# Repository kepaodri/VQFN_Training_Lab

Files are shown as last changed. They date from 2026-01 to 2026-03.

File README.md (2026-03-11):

# VQFN_Training_Lab
PCB Design for a VQFN and DFN package soldering practice board using an LDO regulator.
The purpose of this project is to give different hobbyists without prior experience with this type of package the opportunity to perform soldering tests to reach a good level of mastery. Soldering can be done for example using both reflow hot plate and/or hot air gun. 

## Project Description
This project features a power supply circuit centered on the AP7361C (DFN) LDO regulator. It converts a 2.2V to 6.0V input into a stable 3.3V output with ±1% accuracy. To manage power, SW1 (POWER ON) and SW2 (RESET) pulses are debounced by a 74LVC2G14 Schmitt-Trigger inverter (TSSOP6). A 74AHCT32 (VQFN) OR gate creates a latch, while a 74HCT08 (VQFN) AND gate acts as a kill switch to maintain Enable signal only if the latch is active and RESET is not pressed. 2 green LEDs (D1, D2) provide visual feedback status for the +5V and +3V3 rails.

### Hardware Features
- Input Voltage Range: 2.2V - 6V
- Output Voltage: 3.3V Fixed
- Output voltage accuracy: +-1%
- Max Current: 1.5A

### PCB Features
- Layers: 2
- Thickness: 1.6mm
- Width: 45mm
- Heigth: 50mm

### 3D Render
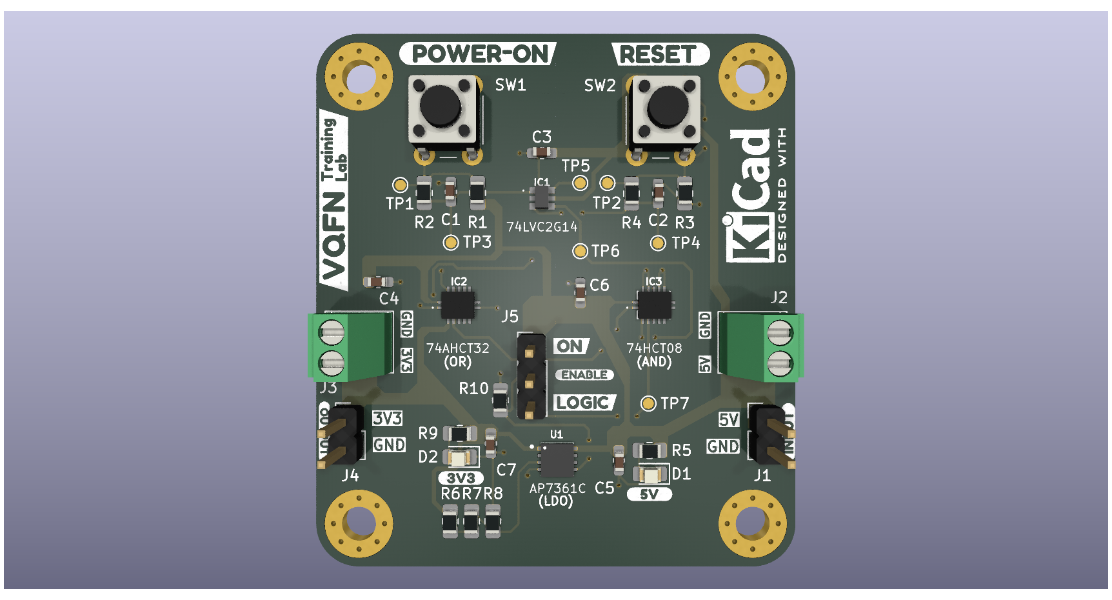
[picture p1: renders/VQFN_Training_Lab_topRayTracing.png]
Top View

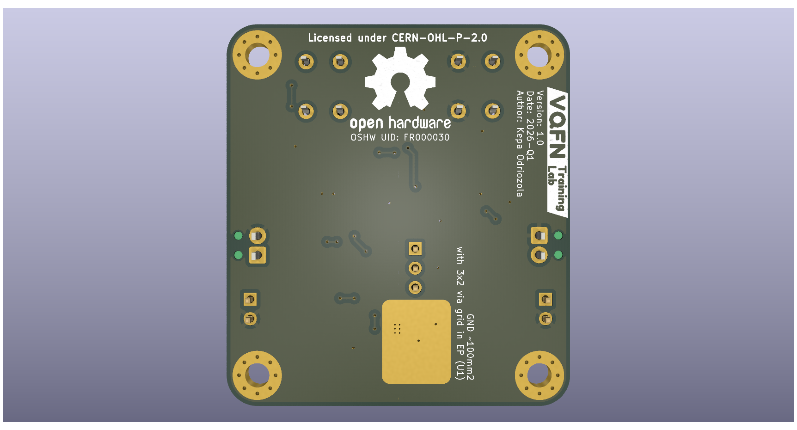
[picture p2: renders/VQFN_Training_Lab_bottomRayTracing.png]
Bot View


## Tools Used
KiCad: 9.0.4

## Licensing and Open Source Hardware
This project is certified as \*\*Open Source Hardware\*\*. 

### Hardware License
The hardware design files are licensed under the \*\*CERN Open Hardware Licence Version 2 - Permissive (CERN-OHL-P-2.0)\*\*. 
> You may redistribute and modify this documentation and build products based on it under the terms of the CERN-OHL-P v2.0.
### Documentation License
All associated documentation, including manuals and images, is licensed under \*\*Creative Commons Attribution-ShareAlike 4.0 International (CC BY-SA 4.0)\*\*.

OSHW_UID

## Disclaimer
\*\*This design is provided "AS-IS" without any express or implied warranties.\*\* The author is not responsible for any damage to equipment, fire, or personal injury resulting from the assembly or use of this PCB.

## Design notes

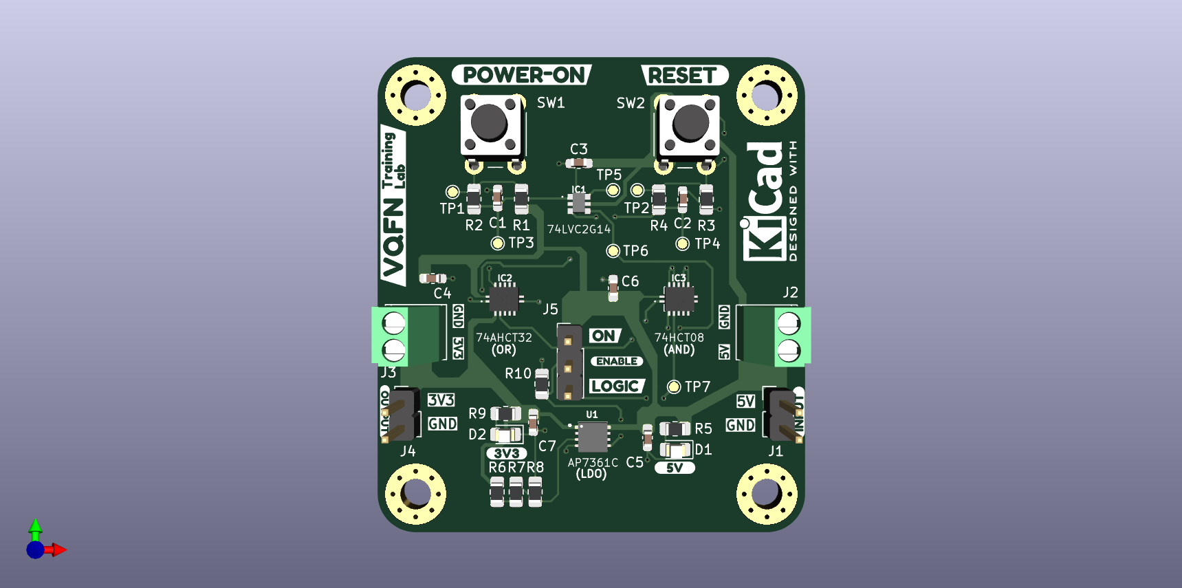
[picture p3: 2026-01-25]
renders/VQFN_Training_Lab_top.png

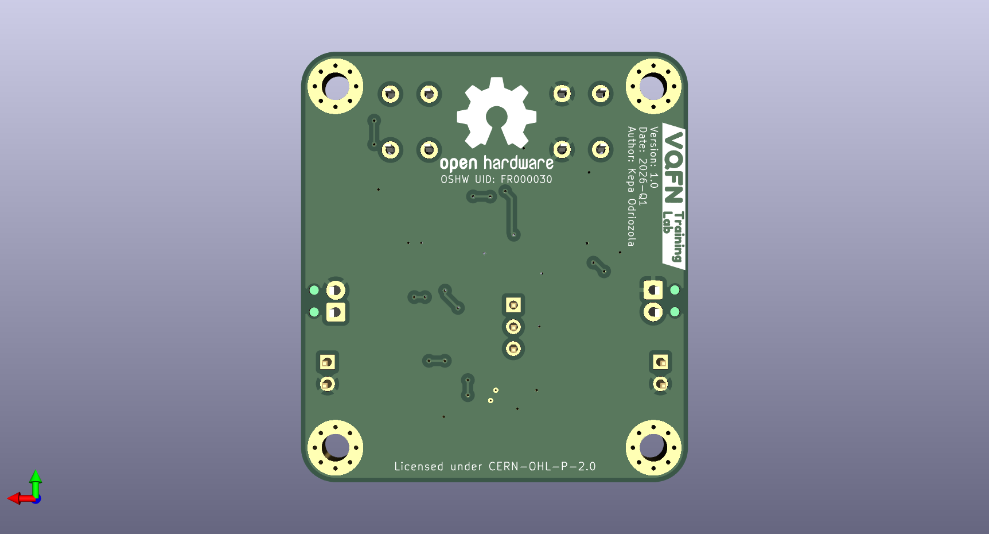
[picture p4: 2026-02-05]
renders/VQFN_Training_Lab_bottom.png

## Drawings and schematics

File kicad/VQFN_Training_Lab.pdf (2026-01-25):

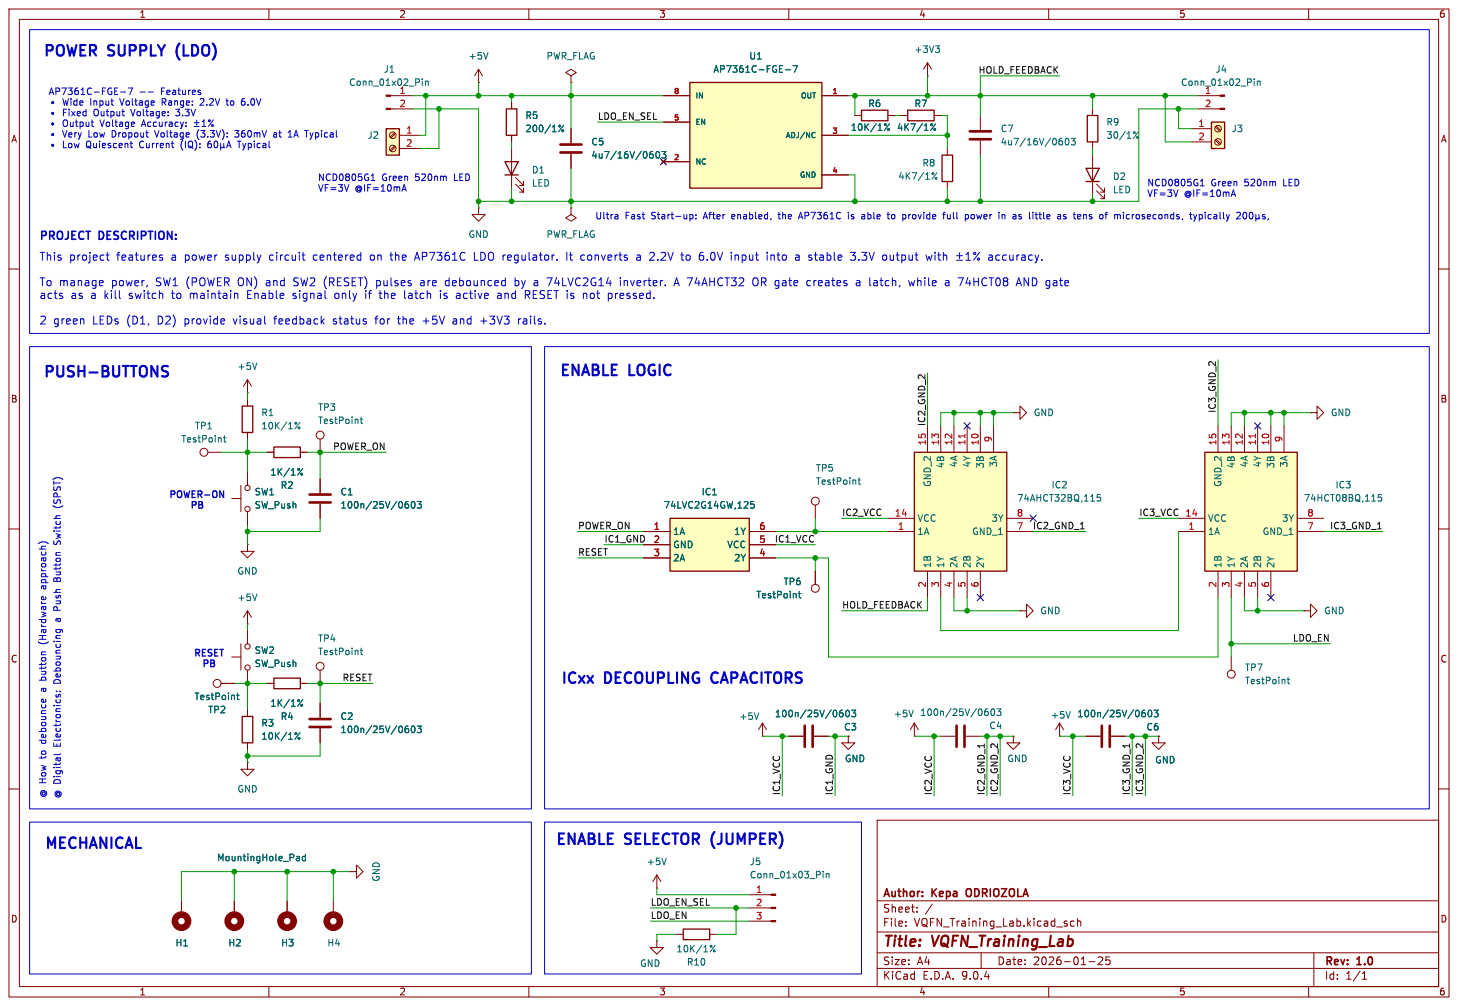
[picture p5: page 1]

+3V3 PWR_FLAG
VF=3V @IF=10mA RESET PB

þÿ "Fixed Output Voltage: 3.3V
þÿ "Output Voltage Accuracy: þÿ±1%
þÿ "Very Low Dropout Voltage (3.3V): 360mV at 1A Typical
þÿ "Low Quiescent Current (IQ): þÿ60µATypical

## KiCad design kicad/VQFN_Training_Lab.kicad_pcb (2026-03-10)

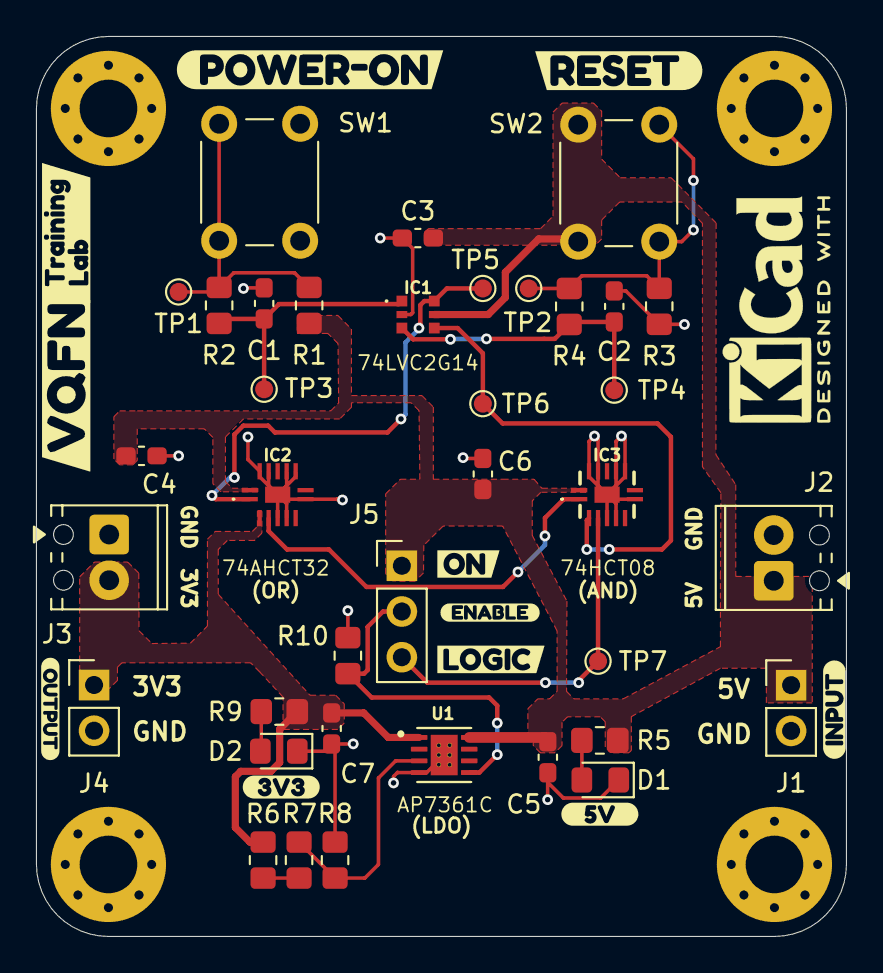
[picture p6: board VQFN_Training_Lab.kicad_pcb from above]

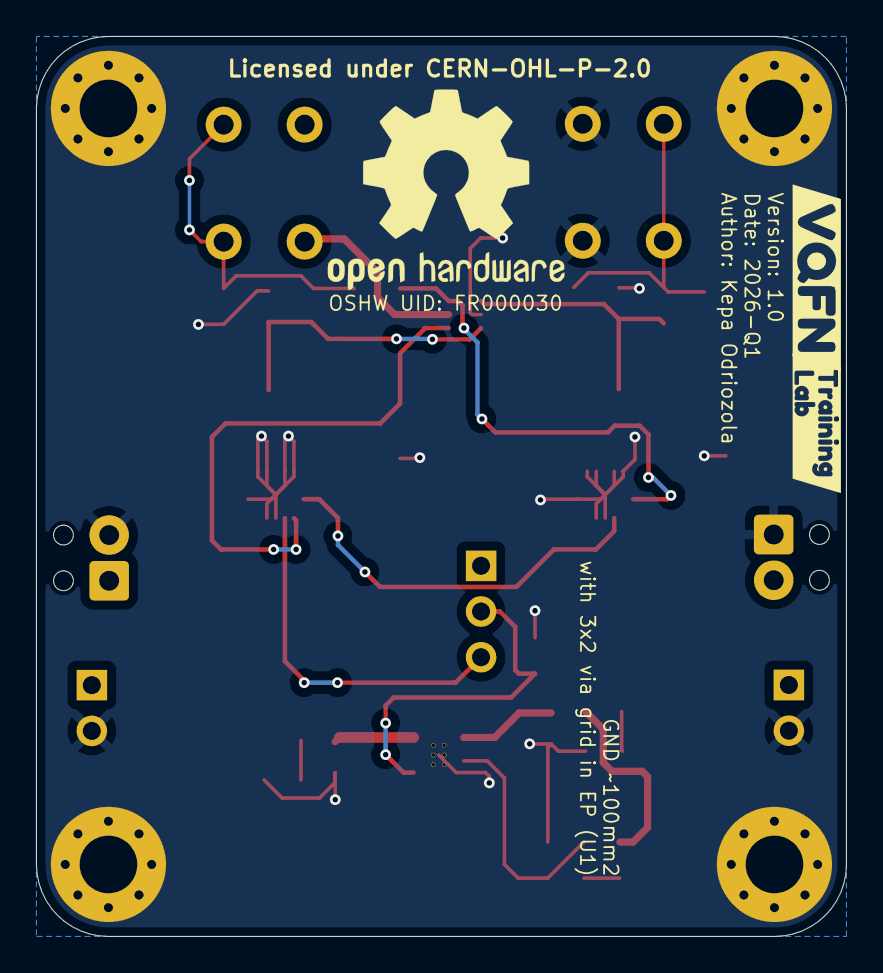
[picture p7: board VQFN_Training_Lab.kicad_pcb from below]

Board: 2 copper layers, 45.0 x 50.0 mm, 54 parts (2 on the bottom side), 16 nets.

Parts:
C1, C2, C3, C4, C6: 100n/25V/0603; C_0603_1608Metric_Pad1.08x0.95mm_HandSolder
C5, C7: 4u7/16V/0603; C_0603_1608Metric_Pad1.08x0.95mm_HandSolder
D1, D2: LED; LED_0805_2012Metric_Pad1.15x1.40mm_HandSolder
H1, H2, H3, H4: MountingHole_Pad; MountingHole_3.2mm_M3_Pad_Via
IC1: 74LVC2G14GW,125; 74LVC2G14GW125
IC2: 74AHCT32BQ,115; 74AHCT32BQ115
IC3: 74HCT08BQ,115; 74HCT08BQ115
J1, J4: Conn_01x02_Pin; PinHeader_1x02_P2.54mm_Vertical
J2, J3: Screw_Terminal_01x02; TerminalBlock_Phoenix_MPT-0,5-2-2.54_1x02_P2.54mm_Horizontal
J5: Conn_01x03_Pin; PinHeader_1x03_P2.54mm_Vertical
R1, R3, R6, R10: 10K/1%; R_0805_2012Metric_Pad1.20x1.40mm_HandSolder
R2, R4: 1K/1%; R_0805_2012Metric_Pad1.20x1.40mm_HandSolder
R5: 200/1%; R_0805_2012Metric_Pad1.20x1.40mm_HandSolder
R7, R8: 4K7/1%; R_0805_2012Metric_Pad1.20x1.40mm_HandSolder
R9: 30/1%; R_0805_2012Metric_Pad1.20x1.40mm_HandSolder
SW1, SW2: SW_Push; SW_PUSH_6mm_H5mm
TP1, TP2, TP3, TP4, TP5, TP6, TP7: TestPoint; TestPoint_Pad_D1.0mm
U1: AP7361C-FGE-7; SON65P300X300X63-9N
kibuzzard-695A7D8B: G***; kibuzzard-695A7D8B
kibuzzard-695A7DB0: G***; kibuzzard-695A7DB0
kibuzzard-695A7DF5: G***; kibuzzard-695A7DF5
kibuzzard-695A7F36: G***; kibuzzard-695A7F36
kibuzzard-695A7F50: G***; kibuzzard-695A7F50
kibuzzard-695C2DAE, kibuzzard-695C2DAE#2: G***; kibuzzard-695C2DAE
kibuzzard-695C2DD0, kibuzzard-695C2DD0#2: G***; kibuzzard-695C2DD0
kibuzzard-695C241E: G***; kibuzzard-695C241E
kibuzzard-695C2423: G***; kibuzzard-695C2423
kibuzzard-696FF104: G***; kibuzzard-696FF104
kibuzzard-696FF158: G***; kibuzzard-696FF158

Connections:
+3V3: C7.1, IC2.2 (1B), J3.2, J4.1, R6.1, R9.1, U1.1 (OUT)
+5V: C3.1, C4.1, C5.1, C6.1, IC1.5 (VCC), IC2.14 (VCC), IC3.14 (VCC), J1.1, J2.1, J5.1, R1.1, R5.1, SW2.2, U1.8 (IN)
/LDO_EN: IC3.3 (1Y), J5.3, TP7.1
/LDO_EN_SEL: J5.2, R10.1, U1.5 (EN)
/POWER_ON: C1.1, IC1.1 (1A), R2.2, TP3.1
/RESET: C2.1, IC1.3 (2A), R4.2, TP4.1
GND: C1.2, C2.2, C3.2, C4.2, C5.2, C6.2, C7.2, D1.1 (K), D2.1 (K), H1.1, H2.1, H3.1, H4.1, IC1.2 (GND), IC2.4 (2A), IC2.5 (2B), IC2.7 (GND_1), IC2.9 (3A), IC2.10 (3B), IC2.12 (4A), IC2.13 (4B), IC2.15 (GND_2), IC3.4 (2A), IC3.5 (2B), IC3.7 (GND_1), IC3.9 (3A), IC3.10 (3B), IC3.12 (4A), IC3.13 (4B), IC3.15 (GND_2), J1.2, J2.2, J3.1, J4.2, R3.2, R8.2, R10.2, SW1.1, U1.4 (GND), U1.9 (GND), U1.10, U1.11, U1.12, U1.13
unnamed: D1.2 (A), R5.2
unnamed: D2.2 (A), R9.2
unnamed: IC1.6 (1Y), IC2.1 (1A), TP5.1
unnamed: IC1.4 (2Y), IC3.2 (1B), TP6.1
unnamed: IC2.3 (1Y), IC3.1 (1A)
unnamed: R1.2, R2.1, SW1.2, TP1.1
unnamed: R3.1, R4.1, SW2.1, TP2.1
unnamed: R6.2, R7.1
unnamed: R7.2, R8.1, U1.3 (ADJ/NC)

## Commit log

2026-01-25 Added gerber and drill files
    [VQFN_Training_Lab-B_Cu.gbr, VQFN_Training_Lab-B_Mask.gbr, VQFN_Training_Lab-B_Paste.gbr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]
2026-01-25 Update README.md
    Added PCB features
2026-01-25 Added KiCad project files
    [VQFN_Training_Lab.kicad_pcb, VQFN_Training_Lab.kicad_sch]
2026-01-25 Added "doc" folder
    Contains Schematic and Datasheet files
2026-03-10 Update and rename VQFN_Training_Lab.kicad_pcb to VQFN_Training_Lab.kicad_pcb
    [VQFN_Training_Lab.kicad_pcb]

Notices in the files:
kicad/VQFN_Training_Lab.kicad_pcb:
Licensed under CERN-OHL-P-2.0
